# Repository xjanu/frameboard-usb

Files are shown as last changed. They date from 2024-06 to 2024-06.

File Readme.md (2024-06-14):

FrameBoard USB
==============

A USB keyboard powered by the Framework Laptop 13 [keyboard matrix](https://frame.work/products/keyboard?v=FRANBKEN05). It was developed as part of the [PV191](https://is.muni.cz/predmet/fi/jaro2024/PV191?lang=en) course at [FI MU](https://www.fi.muni.cz/).

Frameboard USB

## Board

The board schematic and layout can be found in the `board/` directory. It was designed in [KiCad](https://www.kicad.org/).

## Firmware

The firmware is based on the [QMK firmware](https://docs.qmk.fm/). It can be found in the fork of QMK, here: [FrameBoard QMK fork](https://github.com/xjanu/qmk_firmware/)

TODO: instructions for flashing and building

## Errata

TODO

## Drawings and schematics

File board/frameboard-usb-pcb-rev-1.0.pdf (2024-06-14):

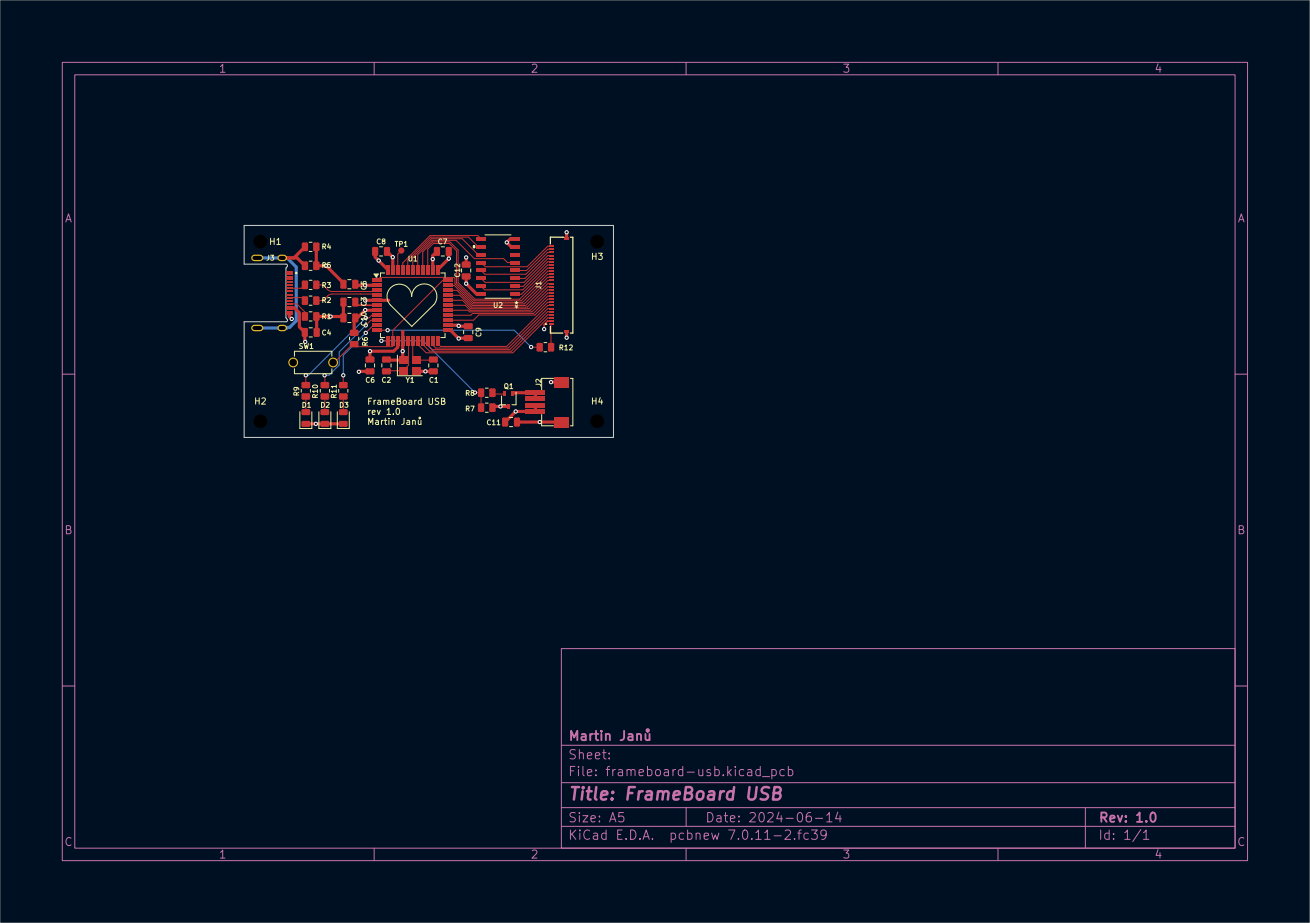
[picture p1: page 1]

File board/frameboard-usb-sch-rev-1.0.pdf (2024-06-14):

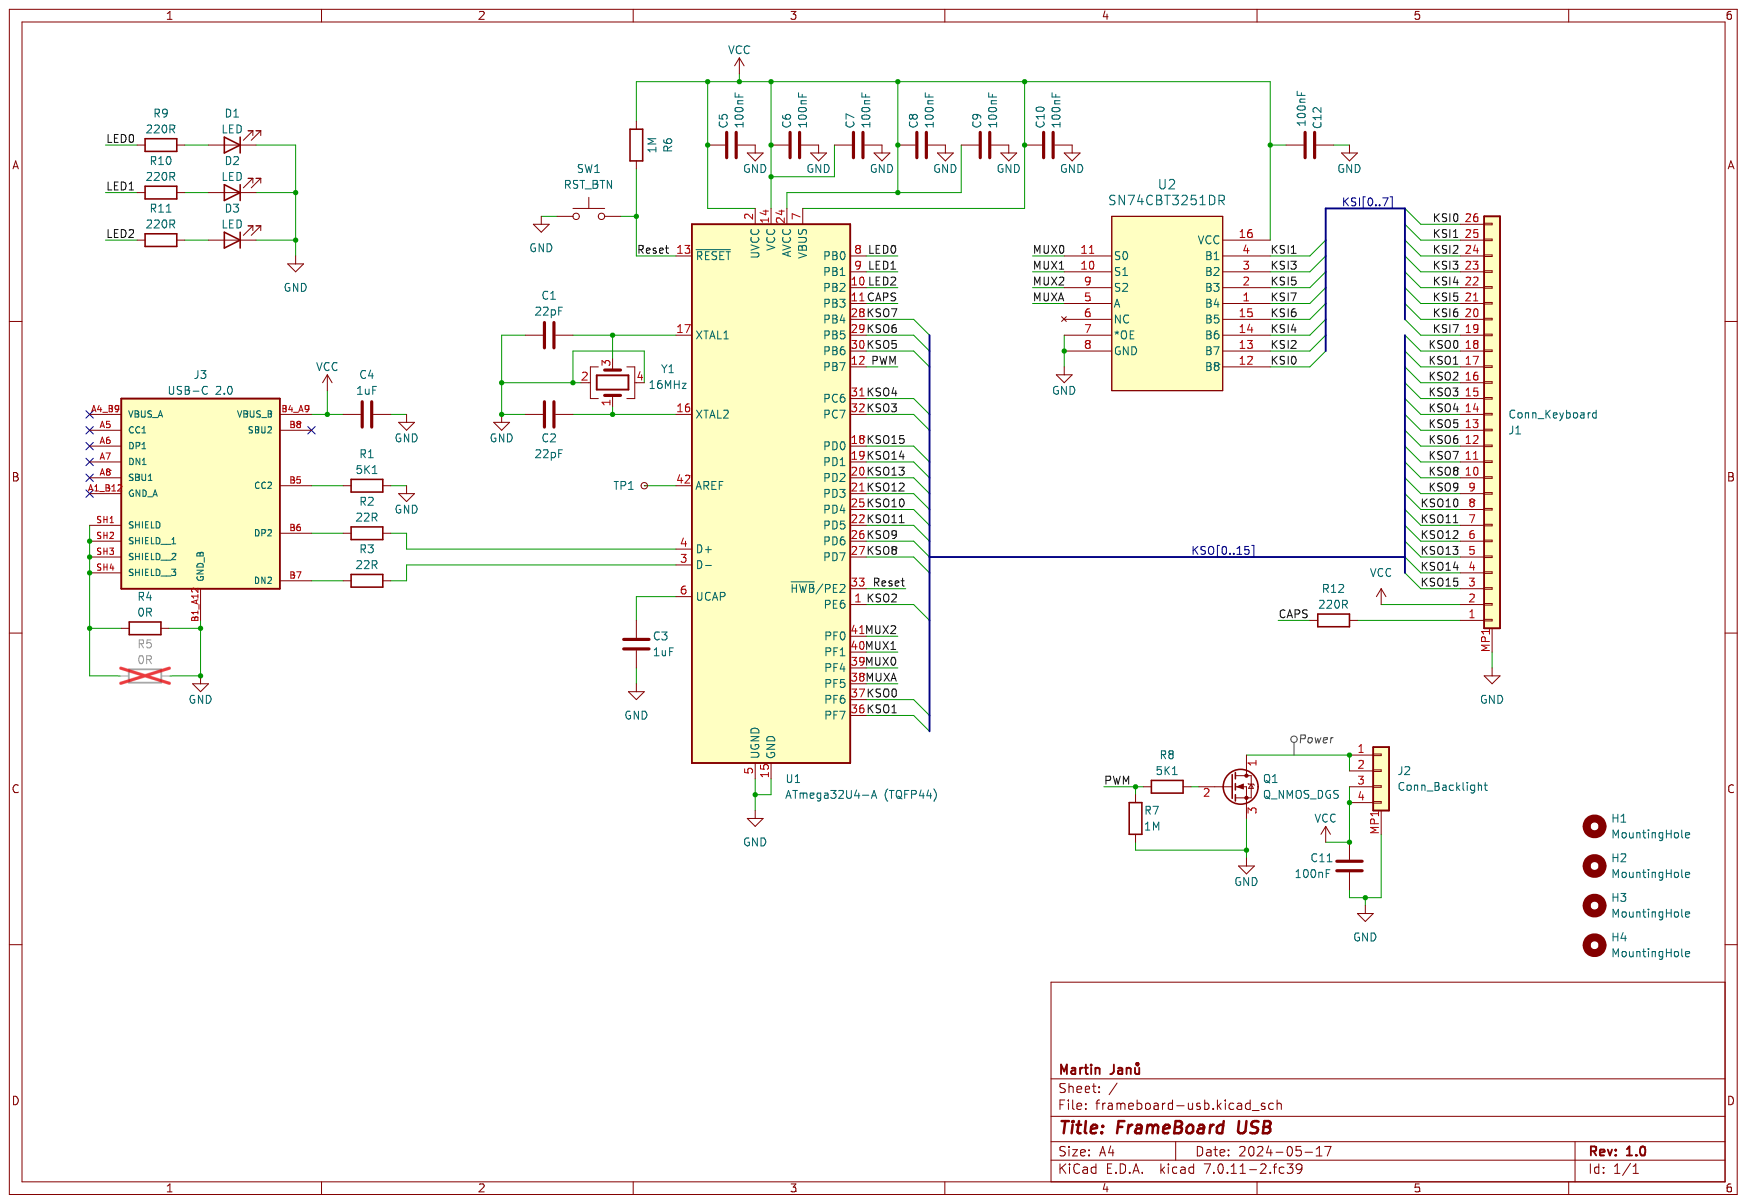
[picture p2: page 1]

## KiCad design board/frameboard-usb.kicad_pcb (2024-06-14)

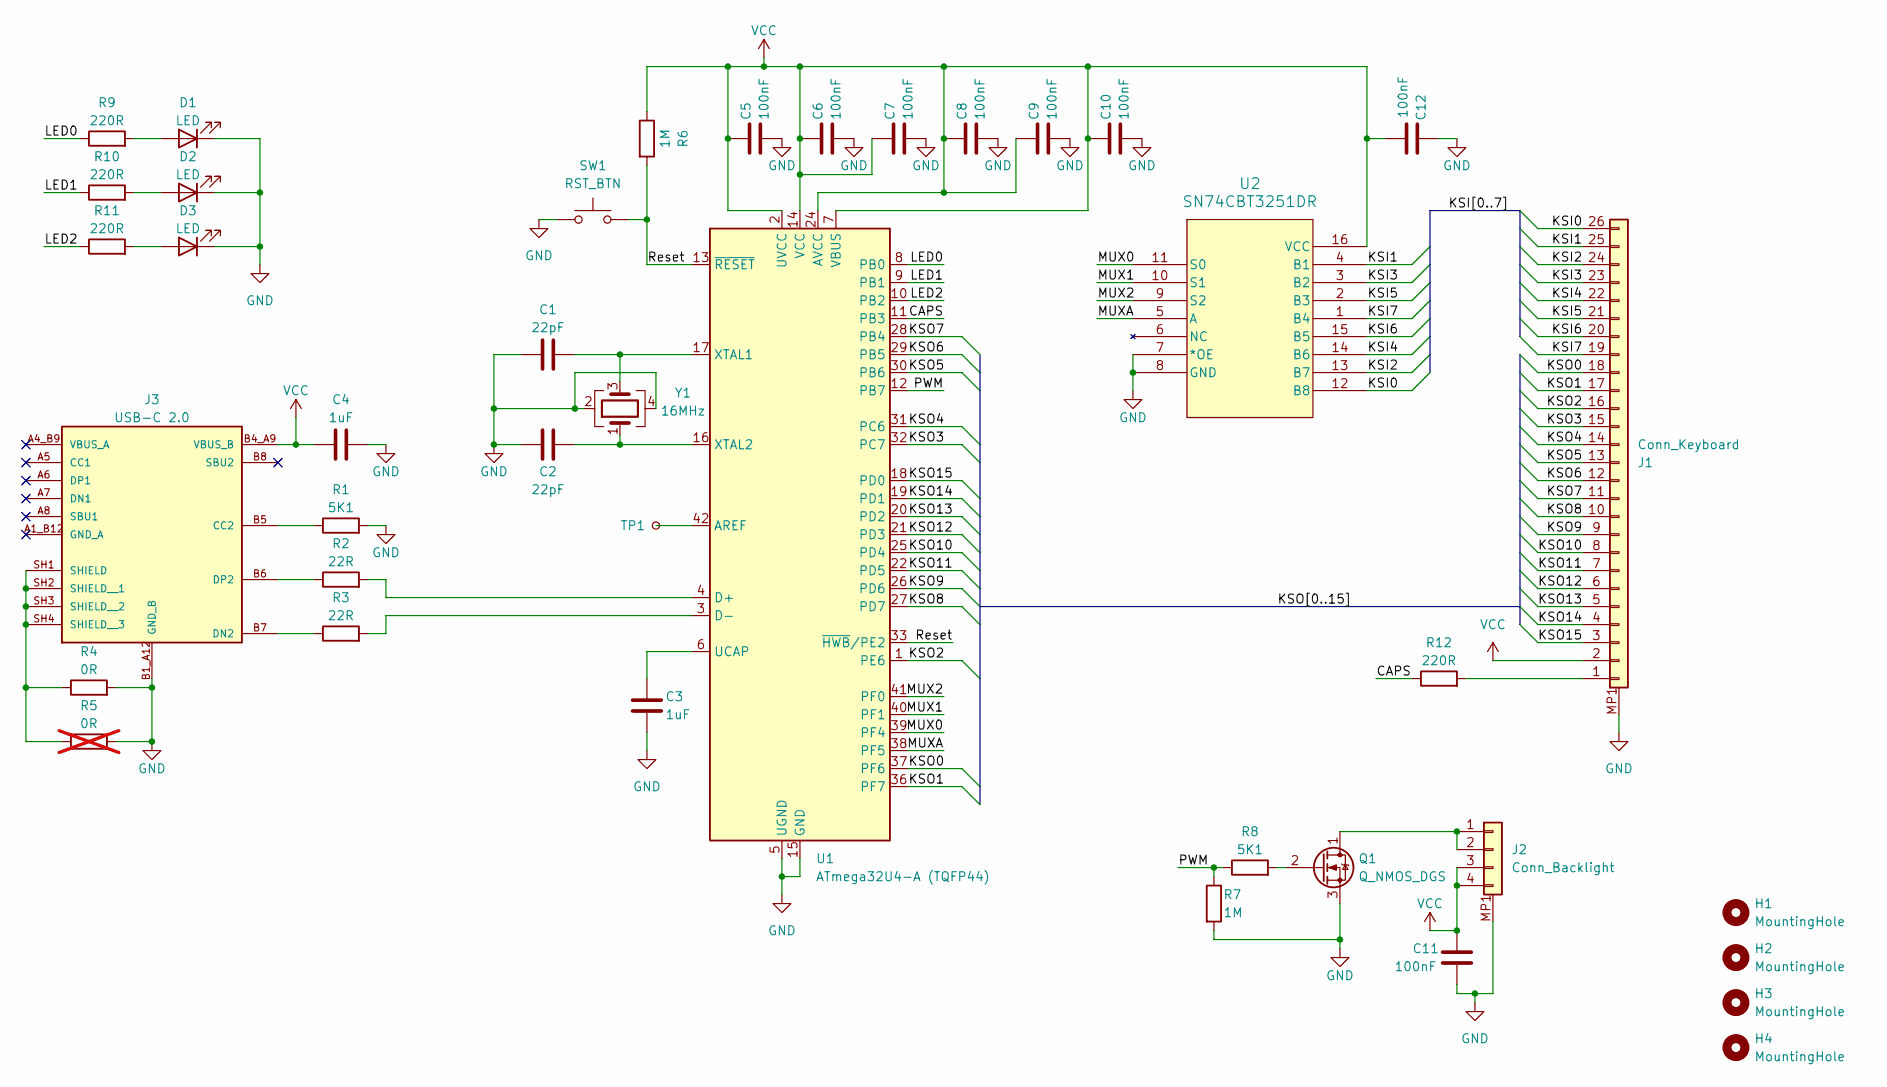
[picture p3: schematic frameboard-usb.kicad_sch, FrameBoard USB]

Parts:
C1, C2: 22pF; C_0805_2012Metric; Digikey C0805C220F1HAC7800
C3, C4: 1uF; C_0805_2012Metric; Digikey CL21B105KAFNNNE
C5, C6, C7, C8, C9, C10, C11, C12: 100nF; C_0805_2012Metric; Digikey CL21B104KBCNNNC
D1, D2, D3: LED; LED_0805_2012Metric; Digikey B1701UY--20D000214U1930
H1, H2, H3, H4: MountingHole; MountingHole_2.2mm_M2
J1: Conn_Keyboard; 046809626210846; Digikey 046809626210846+
J2: Conn_Backlight; conn_backlight; Digikey F518-1A7A1-11004
J3: USB-C 2.0; AMPHENOL_GSB1C4621DS1HR; PARTREV AX1; Digikey GSB1C4621DS1HR
Q1: Q_NMOS_DGS; SOT-323_SC-70; Digikey 4878-2N7002WCT-ND
R1, R8: 5K1; R_0805_2012Metric; Digikey RC0805JR-075K1L
R2, R3: 22R; R_0805_2012Metric; Digikey RC0805FR-0722RL
R4: 0R; R_0805_2012Metric; Digikey RC0805JR-070RL
R5: 0R; R_0805_2012Metric; Digikey RC0805JR-070RL; not fitted
R6, R7: 1M; R_0805_2012Metric; Digikey RC0805FR-071ML
R9, R10, R11, R12: 220R; R_0805_2012Metric; Digikey RC0805FR-07220RL
SW1: RST_BTN; button; Digikey PTS636 SP43 LFS
TP1: TestPoint; testpoint
U1: ATmega32U4-A (TQFP44); TQFP-44_10x10mm_P0.8mm; Digikey ATMEGA32U4-AU
U2: SN74CBT3251DR; SOIC-16_ONS; Digikey SN74CBT3251DR
Y1: 16MHz; Crystal_SMD_3225-4Pin_3.2x2.5mm; Digikey RH100-16.000-18-2030-EXT-TR

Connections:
/CAPS: R12.1, U1.11 (PB3)
/KSI0: J1.26, U2.12 (B8)
/KSI1: J1.25, U2.4 (B1)
/KSI2: J1.24, U2.13 (B7)
/KSI3: J1.23, U2.3 (B2)
/KSI4: J1.22, U2.14 (B6)
/KSI5: J1.21, U2.2 (B3)
/KSI6: J1.20, U2.15 (B5)
/KSI7: J1.19, U2.1 (B4)
/KSO0: J1.18, U1.37 (PF6)
/KSO1: J1.17, U1.36 (PF7)
/KSO2: J1.16, U1.1 (PE6)
/KSO3: J1.15, U1.32 (PC7)
/KSO4: J1.14, U1.31 (PC6)
/KSO5: J1.13, U1.30 (PB6)
/KSO6: J1.12, U1.29 (PB5)
/KSO7: J1.11, U1.28 (PB4)
/KSO8: J1.10, U1.27 (PD7)
/KSO9: J1.9, U1.26 (PD6)
/KSO10: J1.8, U1.25 (PD4)
/KSO11: J1.7, U1.22 (PD5)
/KSO12: J1.6, U1.21 (PD3)
/KSO13: J1.5, U1.20 (PD2)
/KSO14: J1.4, U1.19 (PD1)
/KSO15: J1.3, U1.18 (PD0)
/LED0: R9.1, U1.8 (PB0)
/LED1: R10.1, U1.9 (PB1)
/LED2: R11.1, U1.10 (PB2)
/MUX0: U1.39 (PF4), U2.11 (S0)
/MUX1: U1.40 (PF1), U2.10 (S1)
/MUX2: U1.41 (PF0), U2.9 (S2)
/MUXA: U1.38 (PF5), U2.5 (A)
/PWM: R7.1, R8.1, U1.12 (PB7)
/Reset: R6.2, SW1.2, U1.13 (~RESET), U1.33 (~HWB/PE2)
GND: C1.2, C2.2, C3.2, C4.2, C5.2, C6.2, C7.2, C8.2, C9.2, C10.2, C11.2, C12.1, D1.1 (K), D2.1 (K), D3.1 (K), J1.MP1, J1.MP2, J2.MP1, J2.MP2, J3.B1_A12 (GND_B), Q1.3 (S), R1.2, R4.2, R5.2, R7.2, SW1.1, U1.5 (UGND), U1.15 (GND), U1.23 (GND), U1.35 (GND), U1.43 (GND), U2.7 (*OE), U2.8 (GND), Y1.2, Y1.4
unnamed: D1.2 (A), R9.2
unnamed: D2.2 (A), R10.2
unnamed: D3.2 (A), R11.2
unnamed: J1.1, R12.2
unnamed: J2.1, J2.2, Q1.1 (D)
unnamed: J3.B5 (CC2), R1.1
unnamed: J3.B7 (DN2), R3.1
unnamed: J3.B6 (DP2), R2.1
unnamed: J3.SH1 (SHIELD), J3.SH2 (SHIELD__1), J3.SH3 (SHIELD__2), J3.SH4 (SHIELD__3), R4.1, R5.1
unnamed: Q1.2 (G), R8.2
unnamed: TP1.1, U1.42 (AREF)
unnamed: R2.2, U1.4 (D+)
unnamed: R3.2, U1.3 (D-)
unnamed: C3.1, U1.6 (UCAP)
unnamed: C1.1, U1.17 (XTAL1), Y1.3
unnamed: C2.1, U1.16 (XTAL2), Y1.1
VCC: C4.1, C5.1, C6.1, C7.1, C8.1, C9.1, C10.1, C11.1, C12.2, J1.2, J2.3, J2.4, J3.B4_A9 (VBUS_B), R6.1, U1.2 (UVCC), U1.7 (VBUS), U1.14 (VCC), U1.24 (AVCC), U1.34 (VCC), U1.44 (AVCC), U2.16 (VCC)

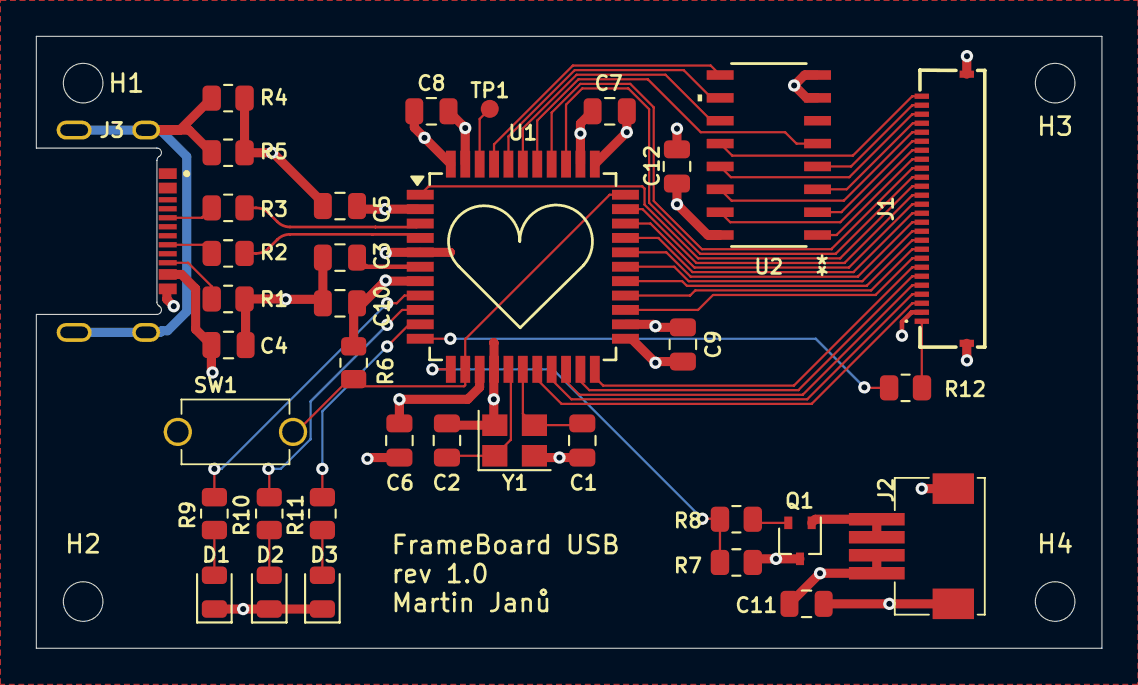
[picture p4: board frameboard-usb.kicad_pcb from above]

Board: 4 copper layers, 59.2 x 34.0 mm, 40 parts (0 on the bottom side), 52 nets.
